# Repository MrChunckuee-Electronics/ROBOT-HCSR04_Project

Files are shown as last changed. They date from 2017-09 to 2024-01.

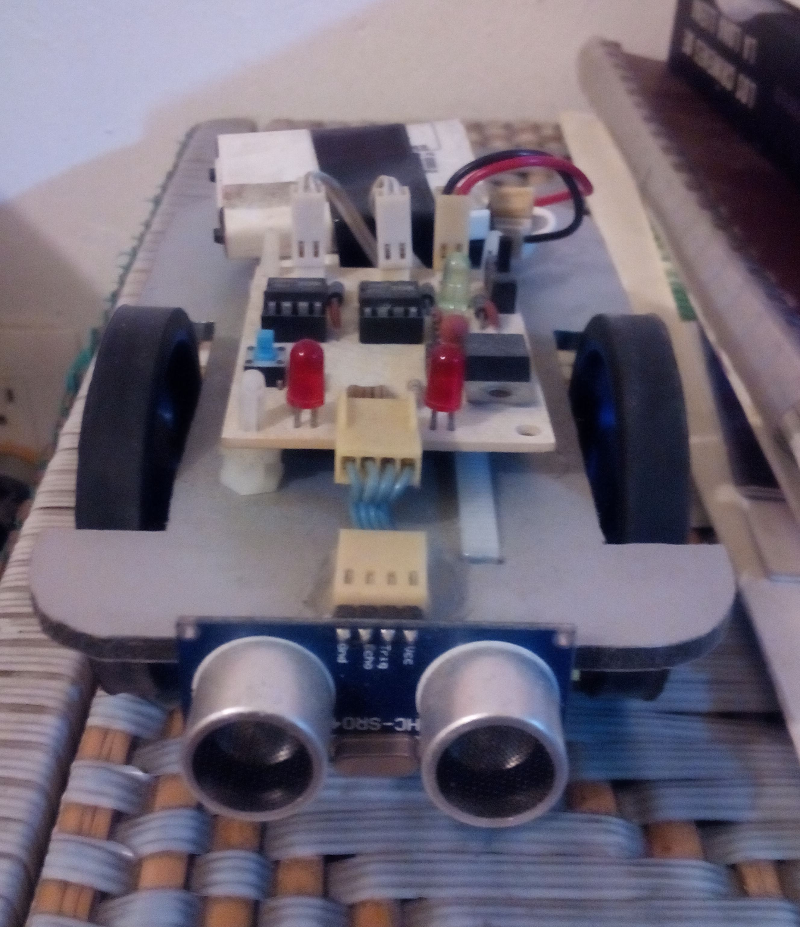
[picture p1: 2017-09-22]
Robot que evita opstaculos.jpg

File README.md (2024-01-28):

# Robot_HC-SR04
***
Para mas archivos de los proyectos de robótica te invito a visitar [MrChuckuee Electronics](http://mrchunckuee.blogspot.mx/p/robotica.html) 

***
Puedes seguirme en:
- [Blogspot](http://mrchunckuee.blogspot.com)
- [Instagram](https://www.instagram.com/mrchunckuee_electronics/)
- [Facebook](https://www.facebook.com/MrChunckueeElectronics)
- [Twitter](https://twitter.com/MrChunckuee)
- [YouTube](https://www.youtube.com/@MrChunckueeElectronics)

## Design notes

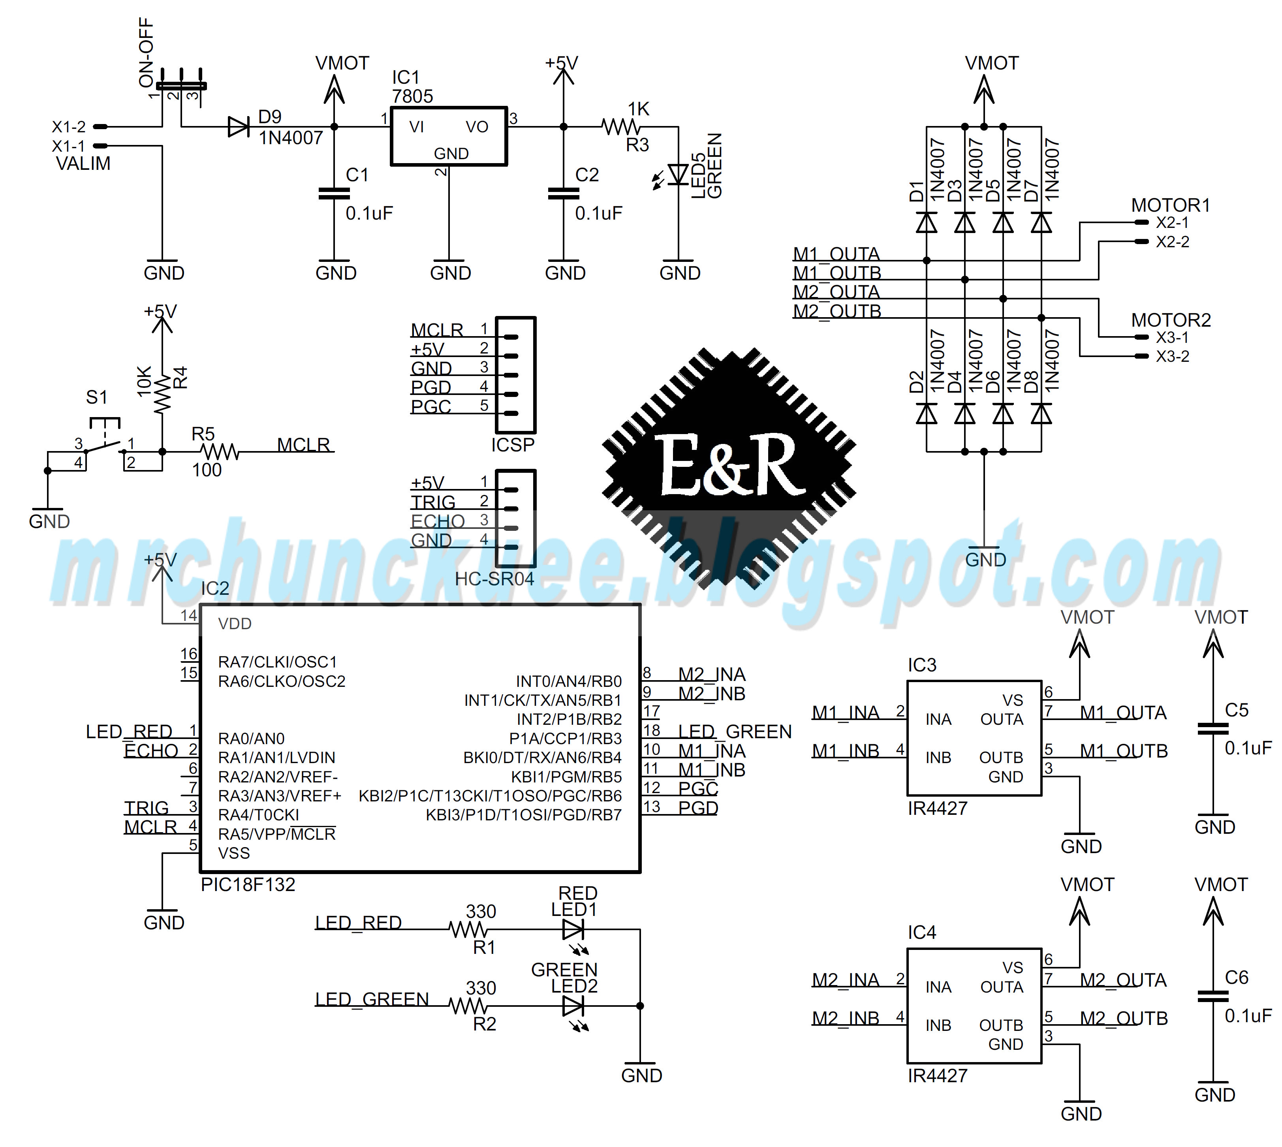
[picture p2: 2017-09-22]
Schematic/Robot_HC-SR04 Schematic.png

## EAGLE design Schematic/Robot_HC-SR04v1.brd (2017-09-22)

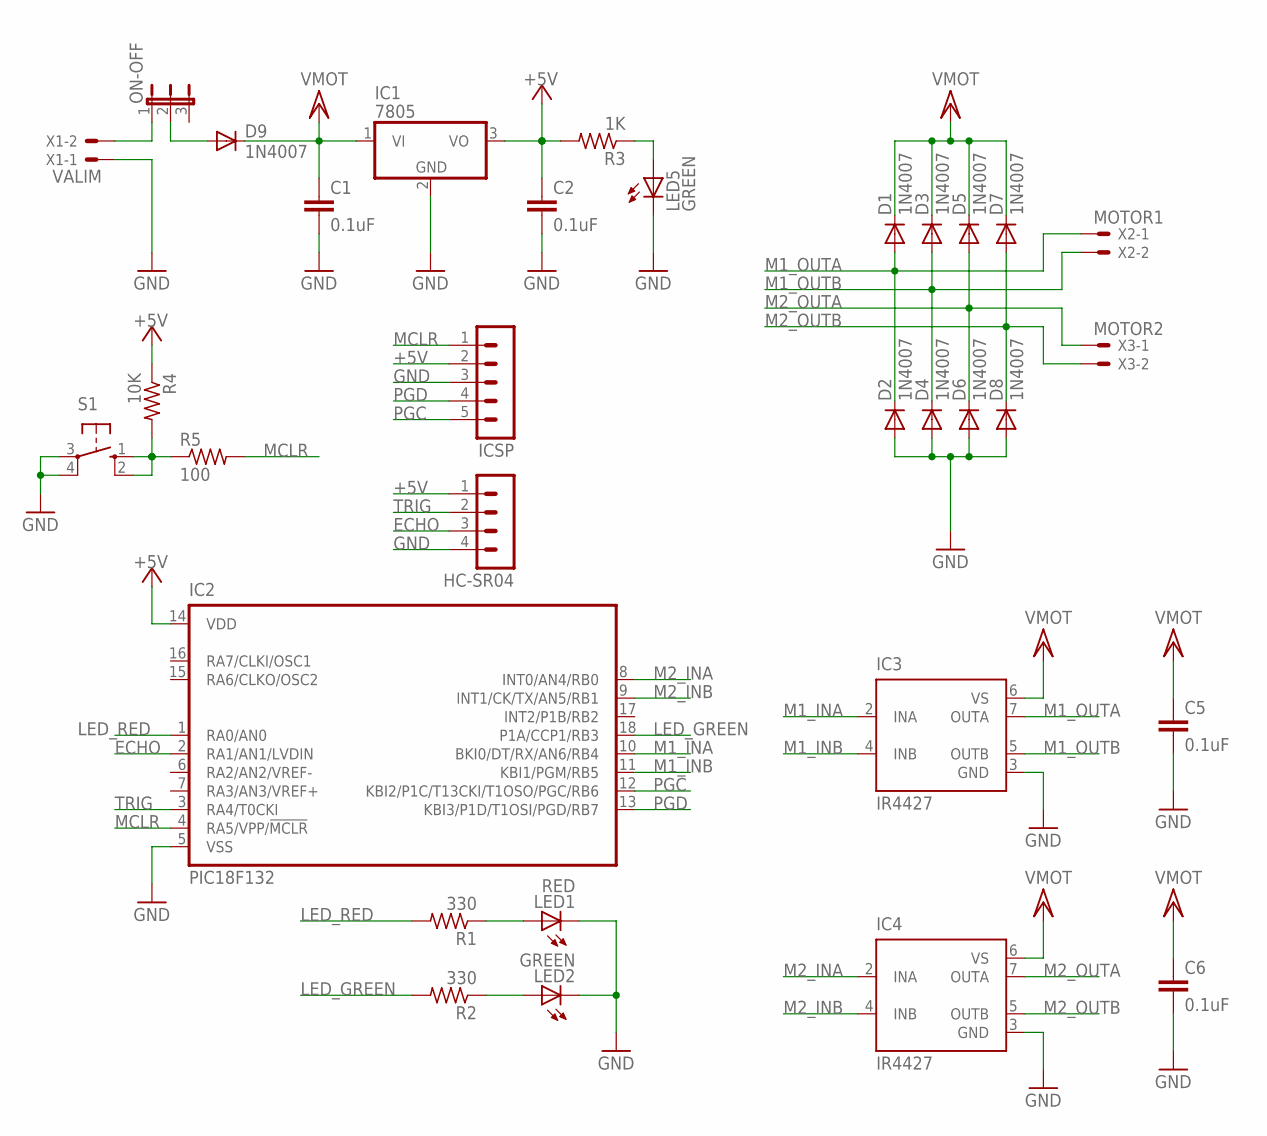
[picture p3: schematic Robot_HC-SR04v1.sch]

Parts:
C1, C2, C5, C6: 0.1uF; C050-024X044
D1, D2, D3, D4, D5, D6, D7, D8, D9: 1N4007; DO41-10
HC-SR04: MA04-1
IC1: 7805; TO220H
IC2: PIC18F132; SO-18W
IC3, IC4: IR4427; DIL08
ICSP: MA05-1
LED1: RED; LED3MM
LED2, LED5: GREEN; LED3MM
ON-OFF: JP2E; JP2
R1, R2: 330; 0207/7
R3: 1K; 0207/7
R4: 10K; 0207/7
R5: 100; 0207/7
S1: 10-XX; B3F-10XX
X1: VALIM; 22-23-2021
X2: MOTOR1; 22-23-2021
X3: MOTOR2; 22-23-2021

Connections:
+5V: C2.1, HC-SR04.1, IC1.3 (VO), IC2.14 (VDD), ICSP.2, R3.2, R4.1
ECHO: HC-SR04.3, IC2.2 (RA1/AN1/LVDIN)
GND: C1.2, C2.2, C5.2, C6.2, D2.A, D4.A, D6.A, D8.A, HC-SR04.4, IC1.2 (GND), IC2.5 (VSS), IC3.3 (GND), IC4.3 (GND), ICSP.3, LED1.K (C), LED2.K (C), LED5.K (C), S1.3, S1.4 (P1), X1.1
LED_GREEN: IC2.18 (P1A/CCP1/RB3), R2.2
LED_RED: IC2.1 (RA0/AN0), R1.2
M1_INA: IC2.10 (BKI0/DT/RX/AN6/RB4), IC3.2 (INA)
M1_INB: IC2.11 (KBI1/PGM/RB5), IC3.4 (INB)
M1_OUTA: D1.A, D2.C, IC3.7 (OUTA), X2.1
M1_OUTB: D3.A, D4.C, IC3.5 (OUTB), X2.2
M2_INA: IC2.8 (INT0/AN4/RB0), IC4.2 (INA)
M2_INB: IC2.9 (INT1/CK/TX/AN5/RB1), IC4.4 (INB)
M2_OUTA: D5.A, D6.C, IC4.7 (OUTA), X3.1
M2_OUTB: D7.A, D8.C, IC4.5 (OUTB), X3.2
MCLR: IC2.4 (RA5/VPP/!MCLR), ICSP.1, R5.2
unnamed: LED5.A, R3.1
unnamed: R4.2, R5.1, S1.1 (S), S1.2 (S1)
unnamed: D9.A, ON-OFF.2
unnamed: ON-OFF.1, X1.2
unnamed: LED1.A, R1.1
unnamed: LED2.A, R2.1
PGC: IC2.12 (KBI2/P1C/T13CKI/T1OSO/PGC/RB6), ICSP.5
PGD: IC2.13 (KBI3/P1D/T1OSI/PGD/RB7), ICSP.4
TRIG: HC-SR04.2, IC2.3 (RA4/T0CKI)
VCC/2: C1.1, C5.1, C6.1, D1.C, D3.C, D5.C, D7.C, D9.C, IC1.1 (VI), IC3.6 (VS), IC4.6 (VS)

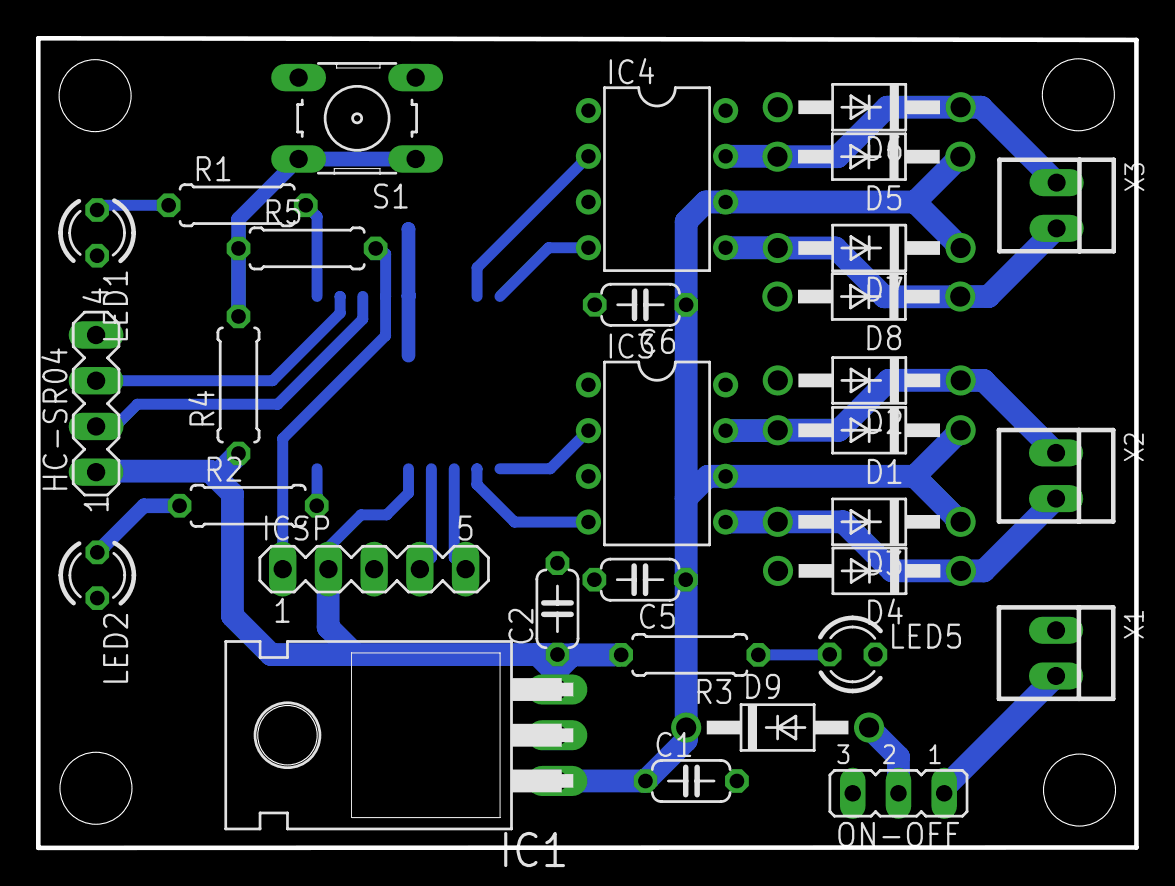
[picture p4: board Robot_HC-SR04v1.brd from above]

Board: 2 copper layers, 61.0 x 45.0 mm, 32 parts (1 on the bottom side), 24 nets.

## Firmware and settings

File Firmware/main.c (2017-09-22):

/*******************************************************************************
 *
 *              ROBOT QUE EVITA OBSTACULOS
 *
 *******************************************************************************
 * FileName:        main.c
 * Processor:       PIC18F1320
 * Complier:        XC8 v1.32
 * Author:          Pedro Sánchez (MrChunckuee)
 * Blog:            http://mrchunckuee.blogspot.com/
 * Email:           mrchunckuee.psr@gmail.com
 * Description:     Robot que evita obstaculos a una distancia de 15cm
 *                  utiliza un sensor ultrasonico HC-SR04
 *                  OSC Interno = 8MHz
 *******************************************************************************
 * Rev.         Date            Comment
 *   v1.00      20/05/2013      Creación del firmware
 ******************************************************************************/
#include <stdio.h>
#include <stdlib.h>
#include <stdint.h>
#include <xc.h>
#include "mcu.h"
#include "word_config.h"

#define _XTAL_FREQ 8000000

void main(void){
    MCU_Init();
    while(1){
        Navegacion();
    }
}

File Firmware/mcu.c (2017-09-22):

/*******************************************************************************
 *
 *              ROBOT QUE EVITA OBSTACULOS
 *
 *******************************************************************************
 * FileName:        mcu.c
 * Processor:       PIC18F1320
 * Complier:        XC8 v1.32
 * Author:          Pedro Sánchez (MrChunckuee)
 * Blog:            http://mrchunckuee.blogspot.com/
 * Email:           mrchunckuee.psr@gmail.com
 * Description:     Robot que evita obstaculos a una distancia de 15cm
 *                  utiliza un sensor ultrasonico HC-SR04
 *                  OSC Interno = 8MHz
 ******************************************************************************/
#include <stdio.h>
#include <stdlib.h>
#include <stdint.h>
#include <xc.h>
#include "mcu.h"

#define _XTAL_FREQ 8000000

enum{AVANZAR, RETROCEDER, GIRO_DER, GIRO_IZQ, PARO};

unsigned int DISTANCIA, DISTANCIA_DER, DISTANCIA_IZQ;

void MCU_Init(void){
    OSCCONbits.IRCF=0b111;  //Oscilador interno a 8MHz
    ADCON1=0xFF; //Configuramos entrada/salida digitales

    //Definimos entradas y salidas
    TRIS_MOTOR_IZQUIERDA_INA=OUTPUT;
    TRIS_MOTOR_IZQUIERDA_INB=OUTPUT;
    TRIS_MOTOR_DERECHA_INA=OUTPUT;
    TRIS_MOTOR_DERECHA_INB=OUTPUT;
    TRIS_LED_DERECHA=OUTPUT;
    TRIS_LED_IZQUIERDA=OUTPUT;
    TRIS_TRIG=OUTPUT; //Pin TRIG del HC-SR04 como salida
    TRIS_ECHO=INPUT; //Pin ECHO del HC-SR04 como entrada

    //Limpiamos los puertos
    PORTA=CLEAR;
    PORTB=CLEAR;
}

void Navegacion(void){
    DISTANCIA=Medir_Distancia();
    if(DISTANCIA>15){
        Opcion_Movimiento(AVANZAR);
    }
    else {
        Opcion_Movimiento(PARO);
        Opcion_Movimiento(GIRO_DER);
        Delay_MS(1000);
        Opcion_Movimiento(PARO);
        DISTANCIA_DER=Medir_Distancia();
        Opcion_Movimiento(GIRO_IZQ);
        Delay_MS(2000);
        Opcion_Movimiento(PARO);
        DISTANCIA_IZQ=Medir_Distancia();
        Opcion_Movimiento(GIRO_DER);
        Delay_MS(1000);
        Opcion_Movimiento(PARO);
        if(DISTANCIA_DER>=DISTANCIA_IZQ){
            Opcion_Movimiento(GIRO_DER);
            Delay_MS(1000);
            Opcion_Movimiento(PARO);
        }
        else{
            Opcion_Movimiento(GIRO_IZQ);
            Delay_MS(1000);
            Opcion_Movimiento(PARO);
        }
    }
}

//Rutina para retardos en mS personalizada
void Delay_MS(unsigned int t){
    unsigned int j;
    for(j=0;j<t;j++){
        __delay_ms(1);
    }
}

unsigned int Medir_Distancia(void){
    unsigned int CENTIMETROS=0;
    TRIG=HIGH;
    __delay_us(10); //Retardo de 10uS
    TRIG=LOW;
    while(ECHO==LOW); //Espera flanco de subida por el pin echo
    while(ECHO==HIGH){
        CENTIMETROS++;
        __delay_us(58);
    }
return(CENTIMETROS);
}

void Opcion_Movimiento(unsigned char X){
    switch(X){
        case AVANZAR:
            MOTOR_IZQUIERDA_INA=LOW;
            MOTOR_IZQUIERDA_INB=HIGH;
            MOTOR_DERECHA_INA=LOW;
            MOTOR_DERECHA_INB=HIGH;
        break;
        case RETROCEDER:
            MOTOR_IZQUIERDA_INA=HIGH;
            MOTOR_IZQUIERDA_INB=LOW;
            MOTOR_DERECHA_INA=HIGH;
            MOTOR_DERECHA_INB=LOW;
        break;
        case GIRO_DER:
            MOTOR_IZQUIERDA_INA=LOW;
            MOTOR_IZQUIERDA_INB=HIGH;
            MOTOR_DERECHA_INA=HIGH;
            MOTOR_DERECHA_INB=LOW;
        break;
        case GIRO_IZQ:
            MOTOR_IZQUIERDA_INA=HIGH;
            MOTOR_IZQUIERDA_INB=LOW;
            MOTOR_DERECHA_INA=LOW;
            MOTOR_DERECHA_INB=HIGH;
        break;
        case PARO:
            MOTOR_IZQUIERDA_INA=LOW;
            MOTOR_IZQUIERDA_INB=LOW;
            MOTOR_DERECHA_INA=LOW;
            MOTOR_DERECHA_INB=LOW;
        break;
        default:
        break;
    }
}
